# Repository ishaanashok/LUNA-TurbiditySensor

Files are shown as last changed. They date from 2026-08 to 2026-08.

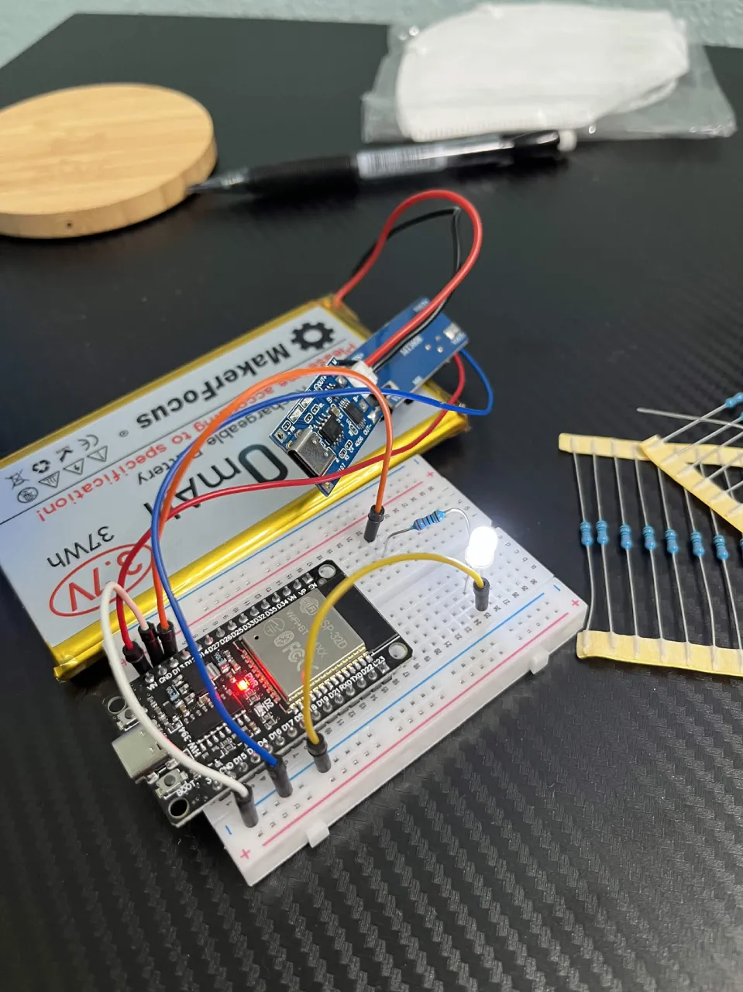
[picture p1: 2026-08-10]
Project_LUNA_Images/Lipo_LED_Test.png

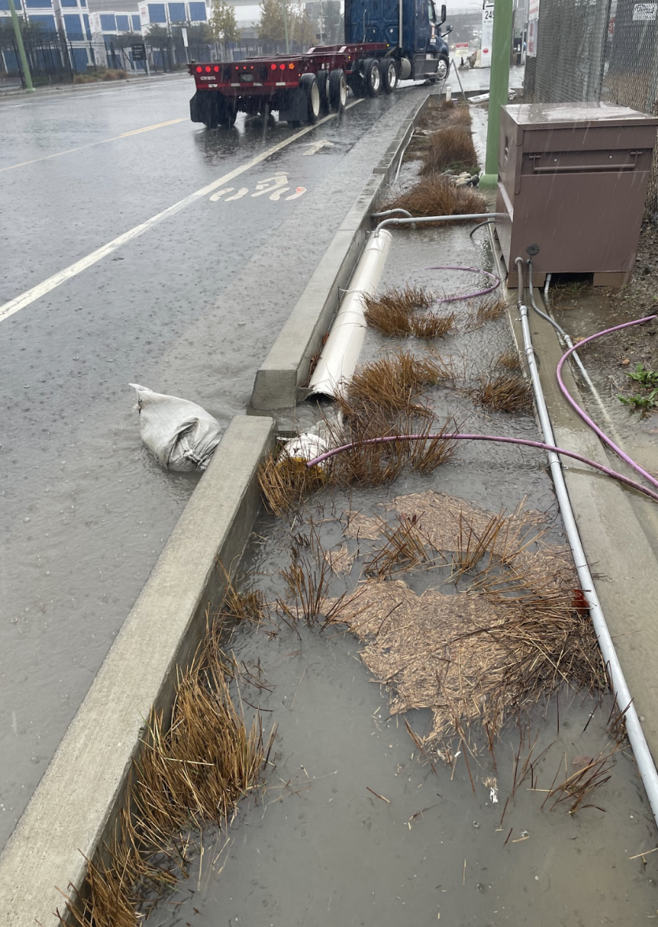
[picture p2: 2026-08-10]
Project_LUNA_Images/Peak_Rainfall_Event.png

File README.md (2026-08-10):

# Project LUNA — Low-Cost Urban Runoff Network for Assessment

Paired turbidity sensors that measure whether a bioretention cell is actually cleaning stormwater.

CAD, firmware, and build images for a two-node system: one sensor at the inlet, one at the outlet.

---

## Background

### What bioretention is

A bioretention cell is a planted basin — often called a rain garden — built into a street, parking lot, or development to treat polluted runoff before it reaches a creek or bay. Water enters from the curb, soaks down through engineered soil and plant roots, and leaves through a perforated underdrain pipe at the bottom. The soil and root layer strips out sediment, metals, and other pollutants along the way.

They are not decorative. Under the San Francisco Bay Municipal Regional Stormwater Permit (MRP), new and redeveloped projects are required to build them. Cities across the Bay Area now maintain thousands of these facilities as regulated infrastructure.

### The problem

Cities are required to build bioretention, but almost never required to measure whether it works.

The permit mandates periodic maintenance inspections — a visual check that the plants are alive, the inlet isn't blocked, and the basin drains. It does not require anyone to measure the water quality going in versus coming out. So a cell can silently stop treating runoff — clogged media, short-circuited flow, failed underdrain — while continuing to pass every inspection it gets.

The reason nobody measures is cost. A professional water-quality monitoring station runs roughly $5,000 to $10,000 per site once you add the sensor, logger, modem, power, and enclosure. At that price a city can instrument a handful of showcase sites, not the hundreds it actually manages.

### Why turbidity

Turbidity — how much suspended sediment is in the water, measured in NTU — is the standard proxy for stormwater treatment performance. Sediment carries a large share of the pollutant load, it responds immediately during a storm, and it can be measured optically without reagents or sample collection. If the water leaving a cell is consistently clearer than the water entering it, the cell is working.

---

## What Luna does

Luna is a **paired turbidity-monitoring system** for bioretention facilities. One sensor sits at the inlet and measures the stormwater entering the facility, while another measures the water leaving through the underdrain. Comparing those two readings can help show how the facility is behaving during a storm and flag sites that may need closer inspection.

The system uses low-cost optical sensing rather than an off-the-shelf commercial turbidity probe.

The basic sensing setup uses:

- **850 nm infrared emitter**
- **Phototransistor**
- **ESP32 microcontroller**
- **Local data logging**
- **Custom 3D-printed optical housing**
- **Battery-powered electronics**
- **Waterproof enclosure and mounting**

The outlet sensor is our earlier proof of concept. The main thing we are currently building is the **higher-range inlet sensor**, which has to deal with dirtier water, more sediment, debris, bubbles, and buildup on the optical windows.

---

## Current inlet design

The inlet sensor has gone through several CAD versions as we have tried to make it smaller, easier to seal, and practical for an actual bioretention site.

One of the main features we are experimenting with is a **magnetically coupled wiper** for the optical window.

Sediment and biofilm can build up on the sensing surface over time and slowly change the reading. Our current idea uses a servo on the protected side of the enclosure to move a magnet, which then moves another magnet attached to a wiper on the wet side.

This lets us move the wiper without putting the servo directly in the water or running a rotating shaft through the enclosure.

So far we have:

- Designed multiple inlet enclosure versions
- Tested different layouts for the sensing chamber and wiper
- Added removable/threaded sections for cleaning and repairs
- Redesigned the enclosure after discussing real installation constraints
- Printed the first physical inlet prototype
- Used the physical print to identify problems with size, wiring, strain relief, and component placement

The current inlet prototype is still an early physical version. It is **not waterproof or field-ready yet**.

---

## What still needs to be tested

The next stage is turning the current CAD and printed prototype into a complete working inlet sensor.

We still need to:

- Assemble the inlet sensing electronics
- Determine the best amplifier gain for higher-turbidity water
- Test the magnetic wiper under sediment exposure
- Improve wire routing and strain relief
- Finalize waterproofing and sealing
- Run immersion tests
- Run repeated wet-dry cycles
- Test in moving, sediment-filled water
- Test window fouling and cleaning
- Integrate the inlet and outlet logging
- Prepare the system for pilot deployment

These are the main things the Macondo hardware funding would allow us to complete.

---

## Repository contents

```text
Inlet Sensor/          Current inlet CAD and design iterations
Effluent Sensor/       Earlier proof-of-concept CAD used as reference
SensorCode/            ESP32 sensing and test firmware
SensorWiringDiagrams/  Electronics and wiring documentation
Project_LUNA_Images/   CAD screenshots, prototypes, testing, and site photos
BOM.csv                Parts requested for the current build
```
## Field partners

LUNA is being developed with the people who do this work professionally, and deployed at sites they already monitor.

**San José — Integral Consulting.** Integral runs water-quality monitoring for municipal stormwater programs. They walked the Alviso site with us alongside City stormwater-compliance staff, and shaped the design around what a real site demands: rushing water during events, sediment loading, wet-dry cycling, limited clearance, and access for maintenance crews.

**Oakland — Applied Marine Sciences.** AMS is an environmental sciences firm working on Bay Area stormwater. Paul Salop hosted us at a Port-area site and wrote a letter of support for the project, noting the need for continuous turbidity monitoring that can function through alternating wet and dry conditions — which is precisely the gap LUNA is built for.

Paired deployments at both sites are scheduled for September 2026, ahead of the winter storm season. Partners install and retrieve; LUNA evaluates.

---

## Team

Three high school students in Fremont, California.

- **Lalit Batchu** — business and partnerships
- **Ishaan Ashok** — embedded systems and software
- **Saket Sandru** — mechanical design and prototyping

Selected as a Top 15 finalist for the 2026 Youth Business Venture Competition at Stanford.

---

## Why it matters

Cities have spent enormous sums building green infrastructure to protect their waterways, and have almost no way to know which of it still works. LUNA exists to make that answer cheap enough to ask everywhere — for the price of monitoring one site the conventional way, a city could watch its entire portfolio.

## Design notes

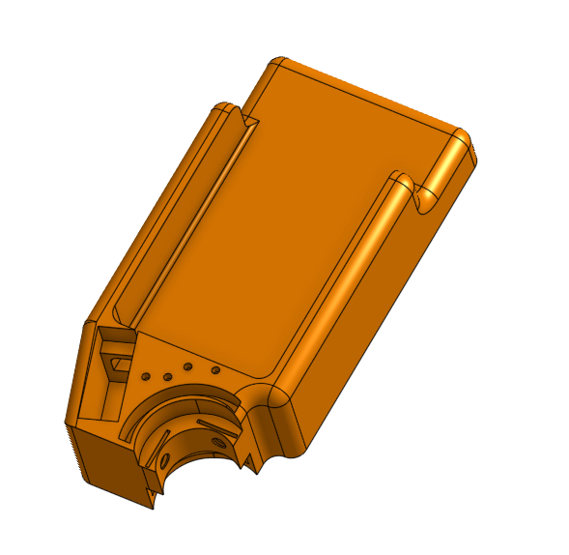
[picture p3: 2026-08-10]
Project_LUNA_Images/v2_inlet_sensor.png

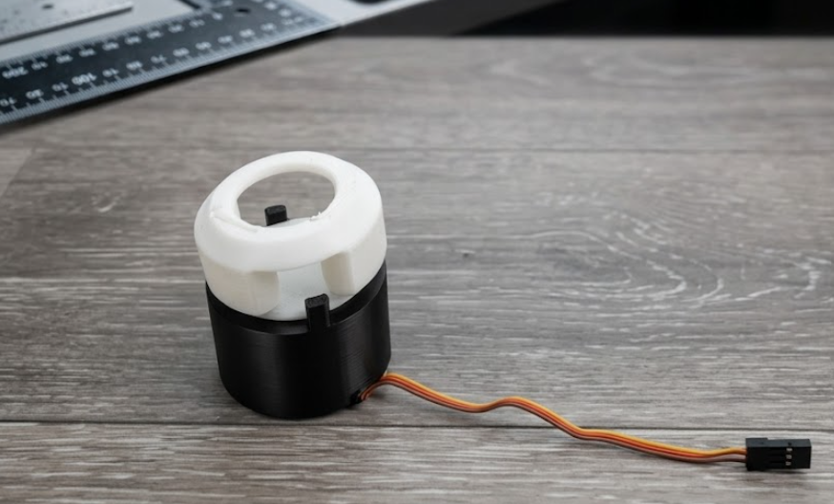
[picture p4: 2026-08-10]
Project_LUNA_Images/v3_inlet_sensor.png

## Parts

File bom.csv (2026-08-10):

Item | Quantity Purchased | Unit Price | Total Price | Purpose | Link
Leingar 2-Pack 1.5in Tri Clamp to 1/2in Hose Barb Adapter | 1 | 14.99 | 14.99 | Flow-testing plumbing
SKLSVIF 2-Pack 1/2in Hose Barb Mini Ball Valve | 1 | 19.99 | 19.99 | Control water flow in test loop
DERNORD 1/2in ID x 5/8in OD Clear Vinyl Hose 25 ft | 1 | 16.69 | 16.69 | Flow-testing tubing
ALITOVE DC 12V 5A Power Supply Adapter | 1 | 12.99 | 12.99 | Power supply for flow-testing setup
ZAOJIAO DC 12V Brushless Water Pump 800 L/h | 1 | 22.99 | 22.99 | Recirculating water for flow testing
uxcell 20mm Sapphire Crystal Lens 1mm thick | 2 | 9.99 | 19.98 | Optical windows for turbidity sensor
ZDBB 1540-pc O-Ring Assortment Kit | 1 | 21.99 | 21.99 | Waterproof sealing and enclosure testing
J-B Weld 8272 MarineWeld Marine Epoxy 2 oz | 1 | 7.29 | 7.29 | Waterproof sealing and sensor assembly
HiLetgo 5-pc Micro SD Card Adapter Reader Modules | 1 | 6.49 | 6.49 | Local sensor data logging
ELEGOO 32-pc Double-Sided PCB Prototype Board Kit | 1 | 9.99 | 9.99 | Assembling sensor electronics
ONJYHK 1000-pc 1% Metal Film Resistor Assortment | 1 | 9.99 | 9.99 | Optical sensing and amplifier circuits
Microchip MCP6002-I/P Dual 1MHz Operational Amplifier 4-pack | 1 | 9.60 | 9.60 | Phototransistor signal amplification
HiLetgo 20-pc PT334-6C Phototransistors | 1 | 5.79 | 5.79 | Optical turbidity detection
CHANZON 100-pc 850nm Infrared LED Emitters | 1 | 8.89 | 8.89 | Infrared light source for turbidity sensing
hiBCTR 3-Pack ADS1115 16-bit ADC Modules | 1 | 12.58 | 12.58 | Higher-resolution optical signal measurement
HiLetgo ESP-WROOM-32 ESP32 Development Board | 2 | 9.99 | 19.98 | Microcontrollers for paired sensor nodes
400-pc 3:1 Adhesive-Lined Heat Shrink Tubing Kit | 1 | 13.99 | 13.99 | Water-resistant wire insulation
ZBLZGP WEIPU SP17 4-pin IP68 Waterproof Connector | 1 | 12.30 | 12.30 | Waterproof electrical connection
uxcell M16x1.5 Waterproof Cable Glands 20-pack | 1 | 9.99 | 9.99 | Sealing wires entering enclosures
Gratury IP67 Waterproof Junction Box | 1 | 24.99 | 24.99 | Protecting sensor electronics in the field
3.3V Mini360 Buck Converter 5-pack | 1 | 8.99 | 8.99 | Voltage regulation for sensor electronics
hiBCTR TP4056 USB-C LiPo Charger Modules 10-pack | 1 | 8.87 | 8.87 | Battery charging and protection
Winfrox 3.7V 5000mAh LiPo Battery | 1 | 13.49 | 13.49 | Portable sensor power
SanDisk 32GB Ultra microSDHC 2-pack | 1 | 34.70 | 34.70 | Local storage for paired sensor nodes
PRODUCT SUBTOTAL |  |  | 347.54
Estimated tax / shipping / handling |  |  | 45.46 | Amount between cart subtotal and checkout total
TOTAL PROJECT PURCHASE |  |  | 393.00

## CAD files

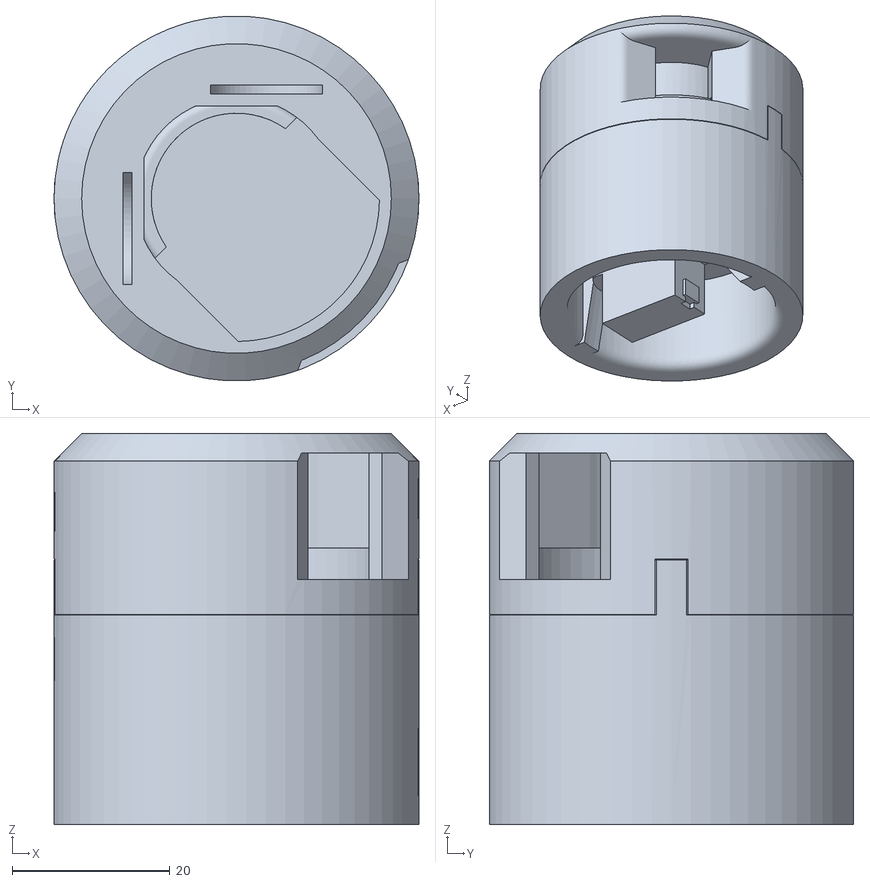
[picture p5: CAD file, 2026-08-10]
Inlet Sensor/v3/InletSensorAssembly.stl
46.2 x 46.1 x 49.5

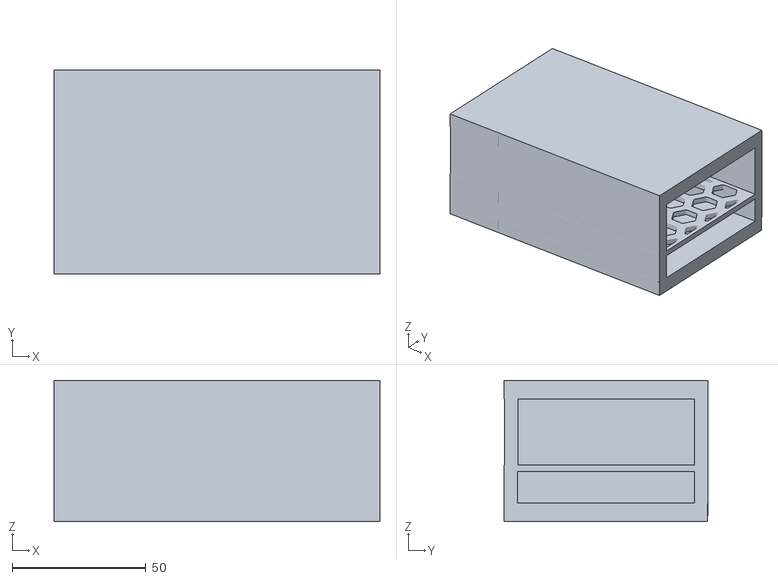
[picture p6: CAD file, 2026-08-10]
Effluent Sensor/Electronics Holder/ElectronicsHolderAssembled.stl
121.9 x 76.4 x 52.8

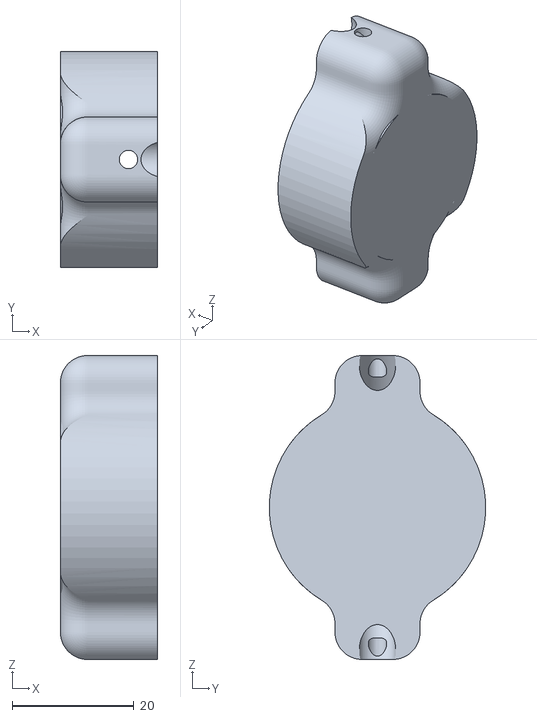
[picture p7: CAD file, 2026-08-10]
Effluent Sensor/EffluentSensor - v2.stl
16.0 x 35.5 x 50.0

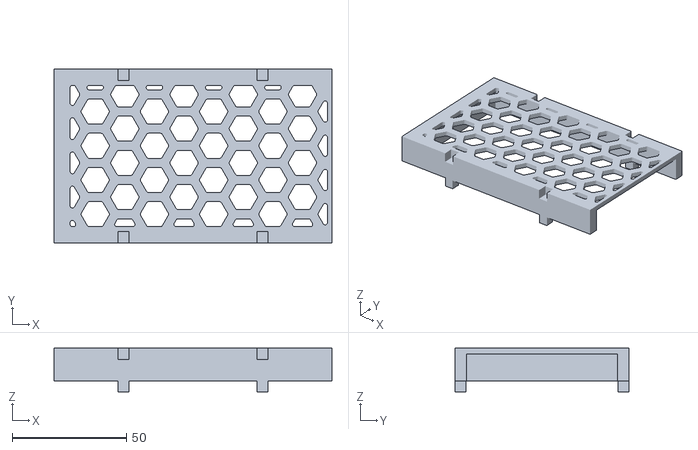
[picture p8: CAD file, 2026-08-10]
Effluent Sensor/Electronics Holder/ElectronicsHolder - BatteryTop.stl
121.9 x 76.2 x 19.2

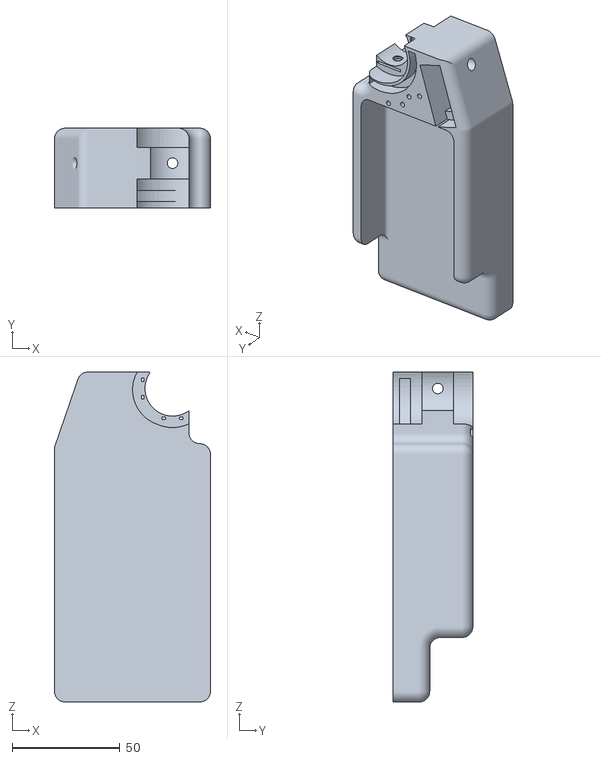
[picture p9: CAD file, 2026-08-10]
Inlet Sensor/Inlet - v1.stl
72.5 x 37.0 x 153.3

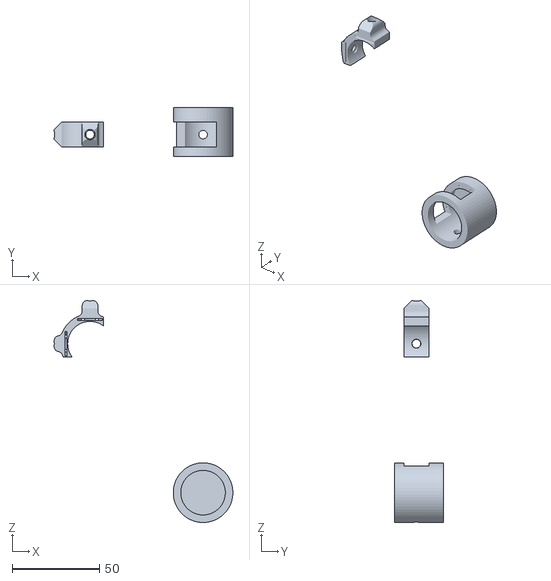
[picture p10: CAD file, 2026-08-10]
Effluent Sensor/EffluentCalibration - v3.stl
102.6 x 28.0 x 127.4

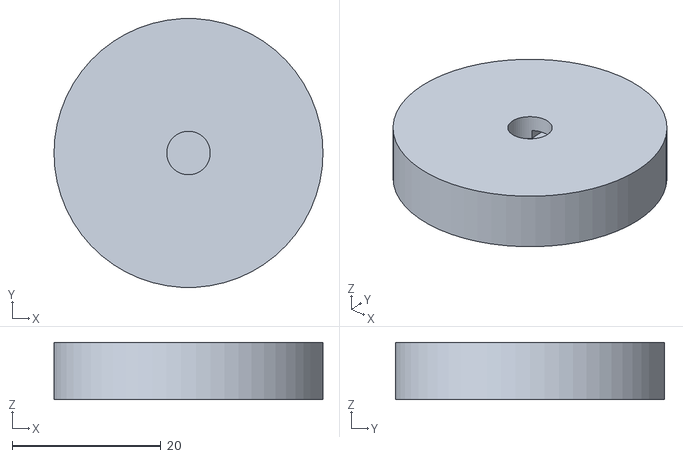
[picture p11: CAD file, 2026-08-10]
Inlet Sensor/v3/InletSensorMagnetBottom.stl
36.2 x 36.2 x 7.70

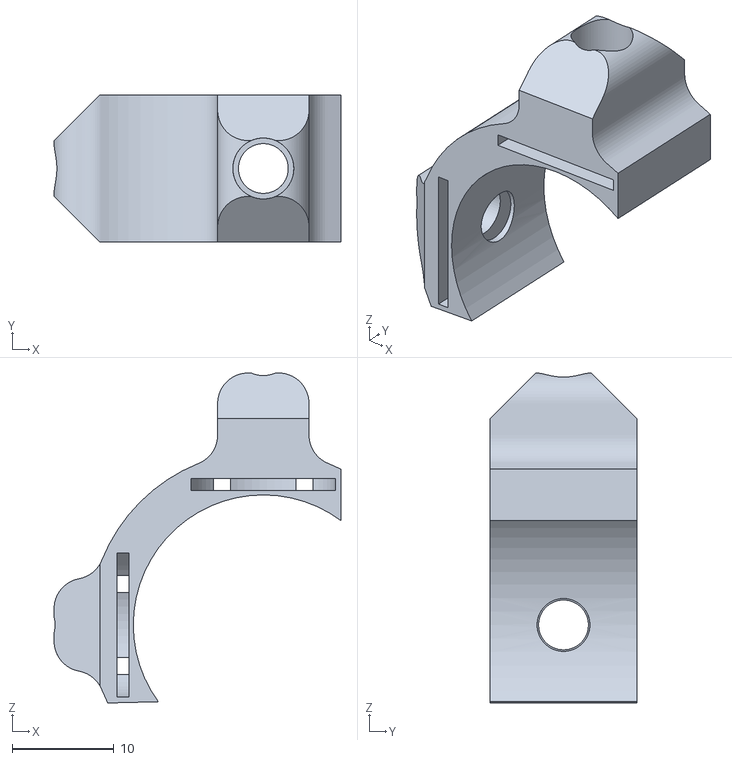
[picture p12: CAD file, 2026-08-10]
Effluent Sensor/EffluenctSensor - v3.stl
28.2 x 14.5 x 32.5

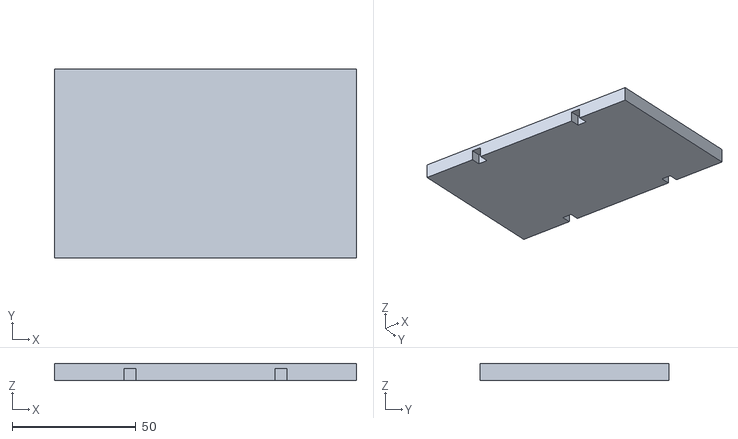
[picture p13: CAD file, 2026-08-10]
Effluent Sensor/Electronics Holder/Top + Bottom.stl
121.9 x 76.2 x 7.00

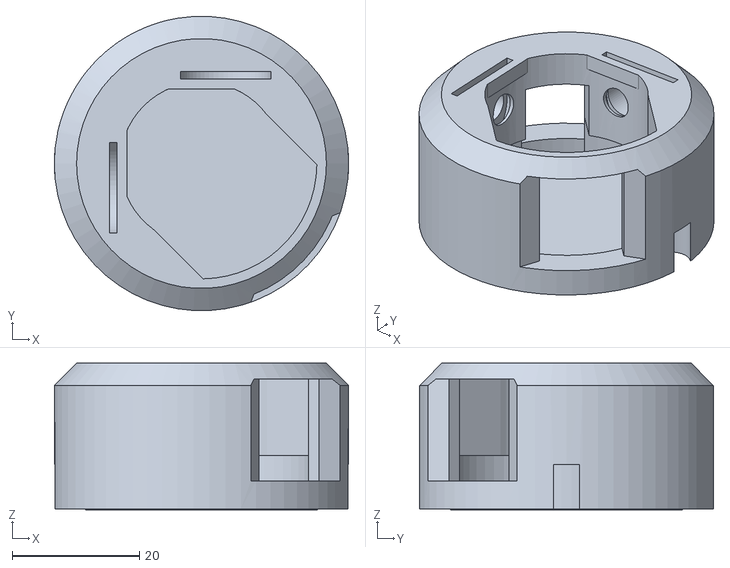
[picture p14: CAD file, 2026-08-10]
Inlet Sensor/v3/InletSensortop.stl
46.2 x 46.1 x 23.0

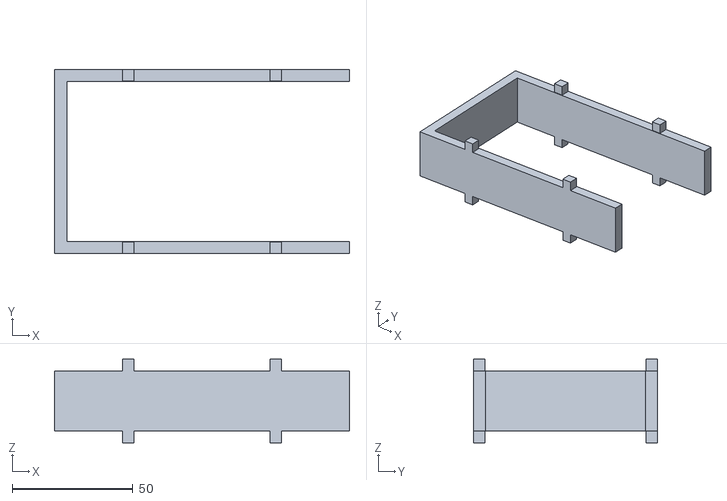
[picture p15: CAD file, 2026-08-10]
Effluent Sensor/Electronics Holder/ESPHolder.stl
121.9 x 76.2 x 34.6

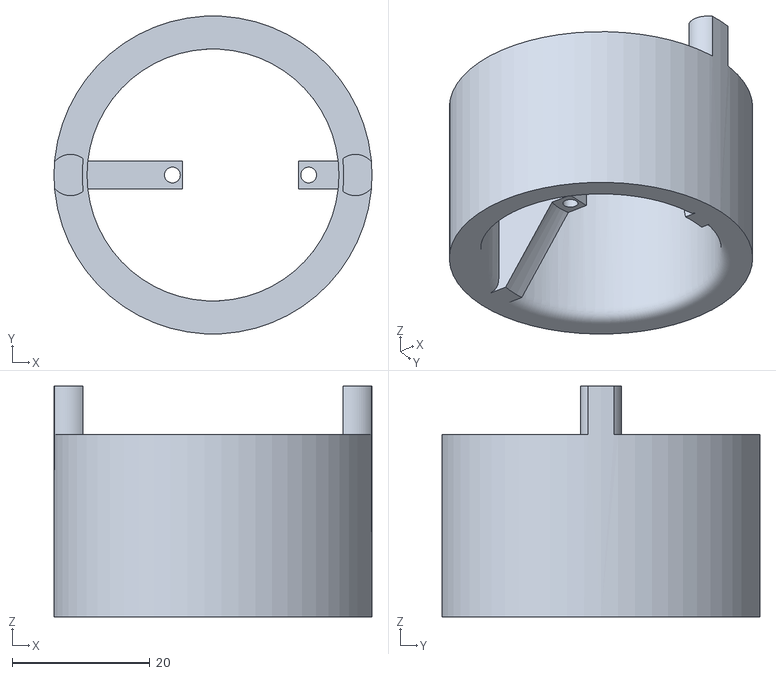
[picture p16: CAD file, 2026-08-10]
Inlet Sensor/v3/InletSensorBottom.stl
46.2 x 46.1 x 33.5

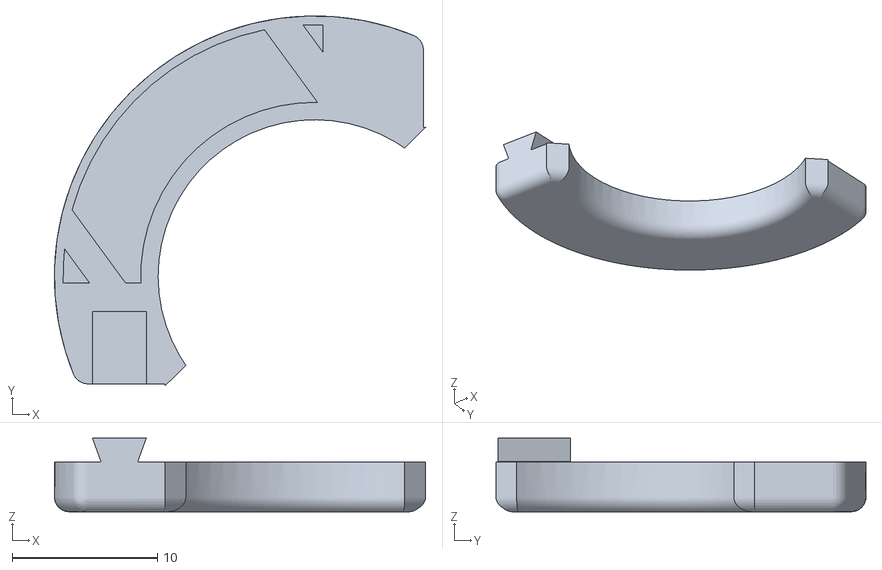
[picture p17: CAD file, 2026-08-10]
Inlet Sensor/v3/InletSensorWiper.stl
25.6 x 25.5 x 5.08

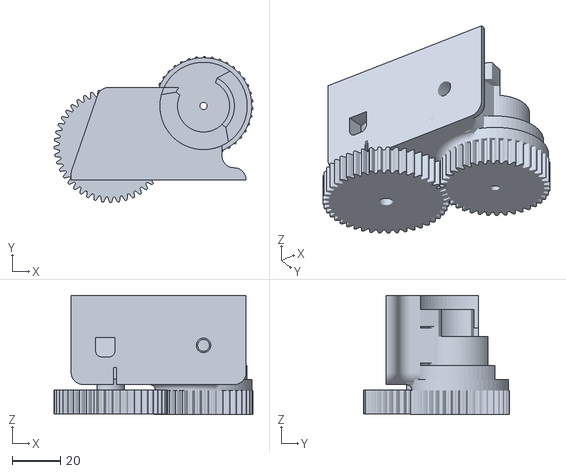
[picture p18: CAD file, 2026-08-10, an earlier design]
Inlet Sensor/v2/InletAssembly.stl
82.5 x 60.5 x 49.5

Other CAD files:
Inlet Sensor/v2/InletWiper.stl
Inlet Sensor/v2/InletSensor.stl
Effluent Sensor/EffluentSensor - v1.stl

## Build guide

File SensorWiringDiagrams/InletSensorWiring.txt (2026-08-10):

                 +-----------------------------------------------------------------------+
                 |                       HELTEC WiFi LoRa 32 (V3)                        |
                 |                                                                       |
                 | [3V3]  [Ve]  [GND]   [GPIO 1]      [GPIO 2]            [GPIO 36/ADC0]  |
                 +--+-----+--+----+---------+------------+----------------------+--------+
                    |     |  |    |         |            |                      |
                    |     |  |    +-----+   |            |                      |
                    |     |  |          |   |            |                      |
  +-----------------+     |  |          |   |            |                      |
  |                       |  |          |   |            |                      |
  |  +--------------------+  |          |   |            |                      |
  |  |                       |          |   |            |                      |
  |  |   DS-M005 SERVO MOTOR |          |   |            |                      |
  |  |   +-------------------+          |   |            |                      |
  |  |   | Red (Power) ------+          |   |            |                      |
  |  |   | Brown (GND) -----------------+   |            |                      |
  |  |   | Yellow (Signal) -----------------+            |                      |
  |  |   +-------------------+                           |                      |
  |  |                                                   |                      |
  |  |   PN2222 TRANSISTOR                               |                      |
  |  |   +---------------+                               |                      |
  |  |   | E (Emitter) --+-------------------------------+                      |
  |  |   | B (Base) -----+-------------------------------+ (via 1k resistor)    |
  |  |   | C (Collector) +-----+                                                |
  |  |   +---------------+     |                                                |
  |  |                         |                                                |
  |  |     220 Ohm             |                                                |
  |  |    +--[ R1 ]------------+                                                |
  |  |    |                                                                     |
  |  |    |   IR EMITTER LED (940nm)                                            |
  |  |    |   +-------------------+                                             |
  |  |    |   | Anode   (+) [Long]|                                             |
  |  |    +---| Cathode (-) [Flat]|                                             |
  |  |        +-------------------+                                             |
  |  |                                                                          |
  |  |   2M Ohm                                                                 |
  |  +--[ R2 ]------------------------------------------------------------------+
  |       |                                                                     |
  +-------+   PHOTOTRANSISTOR (RECEIVER)                                        |
          |   +-------------------+                                             |
          +---| Collector   (+)   |                                             |
              | Emitter     (-)   |---------------------------------------------+
              +-------------------+

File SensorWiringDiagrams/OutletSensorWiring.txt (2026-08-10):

+-------------------------------------------------------+
               |             HELTEC WiFi LoRa 32 (V3)                  |
               |                                                       |
               |   [3V3]      [GND]      [GPIO 2]       [GPIO 36/ADC0] |
               +-----+----------+-----------+------------------+-------+
                     |          |           |                  |
                     |          |           |                  |
   +-----------------+          |           |                  |
   |                            |           |                  |
   |   +------------------------+           |                  |
   |   |                                    |                  |
   |   |   PN2222 TRANSISTOR                |                  |
   |   |   +---------------+                |                  |
   |   |   |   E (Emitter) |----------------+                  |
   |   |   |   B (Base)    |----------------+ (via 1k resistor)|
   |   |   |   C (Collector)|-----+                            |
   |   |   +---------------+     |                            |
   |   |                         |                            |
   |   |     220 Ohm             |                            |
   |   |    +--[ R1 ]------------+                            |
   |   |    |                                                 |
   |   |    |   IR EMITTER LED (940nm)                        |
   |   |    |   +-------------------+                         |
   |   |    |   | Anode   (+) [Long]|                         |
   |   |    +---| Cathode (-) [Flat]|                         |
   |   |        +-------------------+                         |
   |   |                                                      |
   |   |   2M Ohm                                             |
   |   +--[ R2 ]----------------------------------------------+
   |        |                                                 |
   +--------+   PHOTOTRANSISTOR (RECEIVER)                    |
            |   +-------------------+                         |
            +---| Collector   (+)   |                         |
                | Emitter     (-)   |-------------------------+
                +-------------------+

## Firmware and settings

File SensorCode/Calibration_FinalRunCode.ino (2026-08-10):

// --- Pin Configurations (Matched to your ESP32 Sheet) ---
const int emitterPin = 2;    // GPIO2 -> Controls the PN2222 transistor
const int receiverPin = 36;  // GPIO36 / ADC0 -> Reads the phototransistor voltage divider

// --- Sampling Configuration ---
const int numReadings = 1000;      // Fast internal cycles per macro-reading
const int numStandards = 3;        // 4 distinct NTU calibration liquids
const int entriesPerStandard = 6;  // 6 macro-entries taken per liquid standard

float rawSignals[numStandards];    // Cleaned X values for final regression
float targetNTUs[numStandards];    // Y values (Target NTUs)

// --- Active Calibration Coefficients (Chosen by the Auto-Selector) ---
int activeModel = 0;               // 0 = Linear, 1 = Quadratic Polynomial
float lin_a = 0.25, lin_b = 0.00;                 // Linear parameters (y = ax + b)
float poly_a = 0.00, poly_b = 0.25, poly_c = 0.00; // Quadratic parameters (y = ax^2 + bx + c)

// Helper function to capture a single "Net Signal" reading (LED On - LED Off)
float captureNetSignal() {
  long sumLEDOn = 0;
  long sumLEDOff = 0;

  // 1. Measure Ambient Background (LED Off)
  digitalWrite(emitterPin, LOW);
  delay(5); // 5ms settling time for 2MΩ line
  for (int i = 0; i < numReadings; i++) {
    sumLEDOff += analogRead(receiverPin);
  }

  // 2. Measure Total Light (LED On)
  digitalWrite(emitterPin, HIGH);
  delay(5); // 5ms rise time for 2MΩ line
  for (int i = 0; i < numReadings; i++) {
    sumLEDOn += analogRead(receiverPin);
  }
  digitalWrite(emitterPin, LOW); // Turn off LED immediately

  float avgLEDOff = (float)sumLEDOff / numReadings;
  float avgLEDOn = (float)sumLEDOn / numReadings;
  
  return (avgLEDOn - avgLEDOff);
}

// Helper function to pause execution and wait for user numeric input
float waitForUserNTU() {
  while (Serial.available() == 0) {
    delay(50);
  }
  float ntu = Serial.parseFloat();
  while (Serial.available() > 0) {
    Serial.read(); // Clear buffer
  }
  return ntu;
}

// Statistical IQR Filter: Sorts 6 entries, removes outliers, and averages the rest
float filterOutliersAndAverage(float samples[], int n) {
  for (int i = 0; i < n - 1; i++) {
    for (int j = 0; j < n - i - 1; j++) {
      if (samples[j] > samples[j + 1]) {
        float temp = samples[j];
        samples[j] = samples[j + 1];
        samples[j + 1] = temp;
      }
    }
  }

  float q1 = samples[1]; // 25th percentile
  float q3 = samples[4]; // 75th percentile
  float iqr = q3 - q1;

  if (iqr < 0.1) {
    float sum = 0;
    for (int i = 0; i < n; i++) sum += samples[i];
    return sum / n;
  }

  float lowerBound = q1 - 1.5 * iqr;
  float upperBound = q3 + 1.5 * iqr;
  float sumClean = 0;
  int cleanCount = 0;

  for (int i = 0; i < n; i++) {
    if (samples[i] >= lowerBound && samples[i] <= upperBound) {
      sumClean += samples[i];
      cleanCount++;
    } else {
      Serial.print("  ⚠️ Statistical Outlier Detected & Removed: ");
      Serial.println(samples[i], 2);
    }
  }

  if (cleanCount == 0) return samples[2]; 
  return sumClean / cleanCount;
}

// Helper function to calculate 3x3 Determinant (used in Cramer's Rule)
float det3x3(float m[3][3]) {
  return m[0][0]*(m[1][1]*m[2][2] - m[1][2]*m[2][1]) -
         m[0][1]*(m[1][0]*m[2][2] - m[1][2]*m[2][0]) +
         m[0][2]*(m[1][0]*m[2][1] - m[1][1]*m[2][0]);
}

// Fits a 2nd-Order Polynomial (y = ax^2 + bx + c) and calculates R-squared
float fitQuadraticPolynomial(float x[], float y[], int n, float &a, float &b, float &c) {
  float sumX = 0, sumY = 0, sumX2 = 0, sumX3 = 0, sumX4 = 0, sumXY = 0, sumX2Y = 0;
  for (int i = 0; i < n; i++) {
    float x2 = x[i] * x[i];
    sumX += x[i];
    sumY += y[i];
    sumX2 += x2;
    sumX3 += x2 * x[i];
    sumX4 += x2 * x2;
    sumXY += x[i] * y[i];
    sumX2Y += x2 * y[i];
  }

  // Construct the matrices for Cramer's Rule
  float D[3][3] = {
    { sumX4, sumX3, sumX2 },
    { sumX3, sumX2, sumX  },
    { sumX2, sumX,  (float)n }
  };
  
  float Da[3][3] = {
    { sumX2Y, sumX3, sumX2 },
    { sumXY,  sumX2, sumX  },
    { sumY,   sumX,  (float)n }
  };

  float Db[3][3] = {
    { sumX4, sumX2Y, sumX2 },
    { sumX3, sumXY,  sumX  },
    { sumX2, sumY,   (float)n }
  };

  float Dc[3][3] = {
    { sumX4, sumX3, sumX2Y },
    { sumX3, sumX2, sumXY  },
    { sumX2, sumX,  sumY   }
  };

  float detD = det3x3(D);
  if (abs(detD) > 0.001) {
    a = det3x3(Da) / detD;
    b = det3x3(Db) / detD;
    c = det3x3(Dc) / detD;
  } else {
    a = 0.0; b = 0.25; c = 0.0; // Fallback
  }

  // Calculate R-squared for the polynomial curve
  float meanY = sumY / n;
  float ssTot = 0, ssRes = 0;
  for (int i = 0; i < n; i++) {
    ssTot += (y[i] - meanY) * (y[i] - meanY);
    float predictedY = a*x[i]*x[i] + b*x[i] + c;
    ssRes += (y[i] - predictedY) * (y[i] - predictedY);
  }
  return (ssTot > 0) ? (1.0 - (ssRes / ssTot)) : 0.0;
}

// Fits a Linear model (y = ax + b) and calculates R-squared
float fitLinearModel(float x[], float y[], int n, float &a, float &b) {
  float sumX = 0, sumY = 0;
  for (int i = 0; i < n; i++) {
    sumX += x[i];
    sumY += y[i];
  }
  float meanX = sumX / n;
  float meanY = sumY / n;

  float numerator = 0;
  float denominator = 0;
  for (int i = 0; i < n; i++) {
    numerator += (x[i] - meanX) * (y[i] - meanY);
    denominator += (x[i] - meanX) * (x[i] - meanX);
  }

  if (abs(denominator) > 0.001) {
    a = numerator / denominator;
    b = meanY - (a * meanX);
  } else {
    a = 0.25;
    b = 0.00;
  }

  // Calculate R-squared for the linear curve
  float ssTot = 0, ssRes = 0;
  for (int i = 0; i < n; i++) {
    ssTot += (y[i] - meanY) * (y[i] - meanY);
    float predictedY = a*x[i] + b;
    ssRes += (y[i] - predictedY) * (y[i] - predictedY);
  }
  return (ssTot > 0) ? (1.0 - (ssRes / ssTot)) : 0.0;
}

void setup() {
  pinMode(emitterPin, OUTPUT);
  digitalWrite(emitterPin, LOW);

  Serial.begin(115200);
  while (!Serial) { ; }

  Serial.println("\n==============================================");
  Serial.println("   ESP32 Bioretention Monitor - Multi-Curve   ");
  Serial.println("       Dynamic Model Selection Active         ");
  Serial.println("==============================================");

  // --- RUNTIME CALIBRATION SEQUENCE ---
  for (int stepNum = 0; stepNum < numStandards; stepNum++) {
    Serial.print("\n[CALIBRATION LIQUID STANDARD ");
    Serial.print(stepNum + 1);
    Serial.println(" of 4]");
    Serial.println("-> Place the probe into the standard bottle.");
    Serial.println("-> Type the target NTU value and press Enter...");

    targetNTUs[stepNum] = waitForUserNTU();
    
    Serial.println("Stabilizing liquid... Hold perfectly still...");
    delay(3000);
    
    Serial.println("Capturing 6 consecutive data entries...");
    float rawEntries[entriesPerStandard];
    
    for (int entryNum = 0; entryNum < entriesPerStandard; entryNum++) {
      rawEntries[entryNum] = captureNetSignal();
      Serial.print("  Entry "); 
      Serial.print(entryNum + 1); 
      Serial.print(": Raw Net Signal = "); 
      Serial.println(rawEntries[entryNum], 2);
      delay(2000); // 2-second spacing between macro-entries
    }

    rawSignals[stepNum] = filterOutliersAndAverage(rawEntries, entriesPerStandard);

    Serial.print(">> Final Cleaned Average Signal for ");
    Serial.print(targetNTUs[stepNum], 2);
    Serial.print(" NTU is: ");
    Serial.println(rawSignals[stepNum], 2);
    
    delay(3000); 
  }

  // --- DYNAMIC CURVE ANALYSIS ENGINE ---
  Serial.println("\nCalculating regression models...");
  
  float rSquared_linear = fitLinearModel(rawSignals, targetNTUs, numStandards, lin_a, lin_b);
  float rSquared_poly = fitQuadraticPolynomial(rawSignals, targetNTUs, numStandards, poly_a, poly_b, poly_c);

  Serial.println("\n==============================================");
  Serial.println("             REGRESSION EVALUATION            ");
  Serial.println("==============================================");
  Serial.print("1. Linear Model (y = ax + b):\n");
  Serial.print("   -> Formula: y = ("); Serial.print(lin_a, 6); Serial.print(")x + ("); Serial.print(lin_b, 4); Serial.println(")");
  Serial.print("   -> R-squared (fit): "); Serial.println(rSquared_linear, 6);
  
  Serial.print("\n2. Quadratic Polynomial (y = ax^2 + bx + c):\n");
  Serial.print("   -> Formula: y = ("); Serial.print(poly_a, 8); Serial.print(")x^2 + ("); Serial.print(poly_b, 6); Serial.print(")x + ("); Serial.print(poly_c, 4); Serial.println(")");
  Serial.print("   -> R-squared (fit): "); Serial.println(rSquared_poly, 6);
  Serial.println("----------------------------------------------");

  // Determine the best fitting mathematical model
  if (rSquared_poly > rSquared_linear && rSquared_poly <= 1.0) {
    activeModel = 1; // Set active model to Polynomial
    Serial.println(">>> SELECTED MODEL: 2nd-Order Polynomial Curve (Better Fit) <<<");
  } else {
    activeModel = 0; // Set active model to Linear
    Serial.println(">>> SELECTED MODEL: Linear Model (Better Fit) <<<");
  }
  Serial.println("==============================================\n");
  
  delay(5000);
}

void loop() {
  float netSignal = captureNetSignal();
  float cleanSignal = netSignal < 0 ? 0.00 : netSignal;
  float calculatedNTU = 0.00;

  // Execute the mathematical calculation based on the auto-selected model
  if (activeModel == 1) {
    // Quadratic: y = ax^2 + bx + c
    calculatedNTU = (poly_a * cleanSignal * cleanSignal) + (poly_b * cleanSignal) + poly_c;
  } else {
    // Linear: y = ax + b
    calculatedNTU = (lin_a * cleanSignal) + lin_b;
  }

  // Zero-bound check to prevent physically impossible negative NTU values
  if (calculatedNTU < 0) {
    calculatedNTU = 0.00;
  }

  // Print live data stream
  Serial.print("Net Signal: ");
  Serial.print(netSignal, 2);
  Serial.print("  |  Active Model: ");
  Serial.print(activeModel == 1 ? "Quadratic Poly" : "Linear");
  Serial.print("  |  Live Turbidity: ");
  Serial.print(calculatedNTU, 2);
  Serial.println(" NTU");

  delay(2000);
}

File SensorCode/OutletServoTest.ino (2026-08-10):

#include <ESP32Servo.h>

// Create servo object
Servo myServo;

// Define control pin
const int servoPin = 1; // GPIO 1 connected to Yellow signal wire

void setup() {
  Serial.begin(115200);
  delay(1000);
  Serial.println("Starting Positional Servo Control...");

  // Allow standard 50Hz PWM signal for digital servos
  ESP32PWM::allocateTimer(0);
  myServo.setPeriodHertz(50);

  // Attach servo to GPIO 1 with pulse widths mapped to 500us - 2500us
  // (Matched to the DS-M005 datasheet range for full 0° to 180° rotation)
  myServo.attach(servoPin, 500, 2500);
}

void loop() {
  Serial.println("Moving to 0 degrees...");
  myServo.write(0);
  delay(2000);

  Serial.println("Moving to 90 degrees (Center)...");
  myServo.write(90);
  delay(2000);

  Serial.println("Moving to 180 degrees...");
  myServo.write(180);
  delay(2000);
}

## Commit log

2026-08-10 Effluent Sensor CAD Files
    [ESPHolder.stl, EffluenctSensor - v3.stl, EffluentCalibration - v3.stl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]
2026-08-10 Inlet Sensor CAD Files
    [Inlet - v1.stl, InletAssembly.stl, InletSensor.stl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]
2026-08-10 Sensor Code
2026-08-10 Add bill of materials for project components
    [bom.csv]
